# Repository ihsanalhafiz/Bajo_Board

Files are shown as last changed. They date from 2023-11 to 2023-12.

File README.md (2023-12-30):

# Bajo Board (Low Cost Seismic Imaging Sensor Systems based on MEMS Accelerometer)

The Bajo Board or accelerometer sensor system is an integrated sensor system consisting of accelerometer, inclinometer and seismometer sensors. The accelerometer sensor is used to detect vibrations and carry out seismic imaging. The inclinometer sensor is used to detect tilt from monitoring stations. The seismometer sensor is used to calculate the SI value to detect early if there is an earthquake or tectonic activity and send a warning if an earthquake with MMI level 5 or above is detected. It requires voltage input with industry standart 24V, and will provide interface in RS232.

# [Updated] Deploy location and results

## Deploy location
This board was deployed in the pilot project Indonesia Cable Based Tsunameter in NTT, Indonesia in 2 locations. These sensors are used for the seismic imaging, so it receives the accelerometer raw data and not directly converted to earthquake magnitude. that is the ongoing research. 

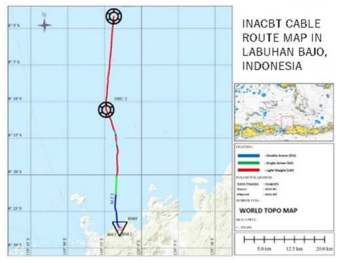
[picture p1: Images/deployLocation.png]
deploy


reference

M. A. Purwoadi, Y. Anantasena, W. W. Pandoe, J. Widodo and A. E. Sakya, "Introduction to Indonesian Cable-based Subsea Tsunameter," 2023 IEEE Underwater Technology (UT), Tokyo, Japan, 2023, pp. 1-6, doi: 10.1109/UT49729.2023.10103368.

## Results from earthquakes
these results show accelerometer raw data from earthquakes.
### First earthquake
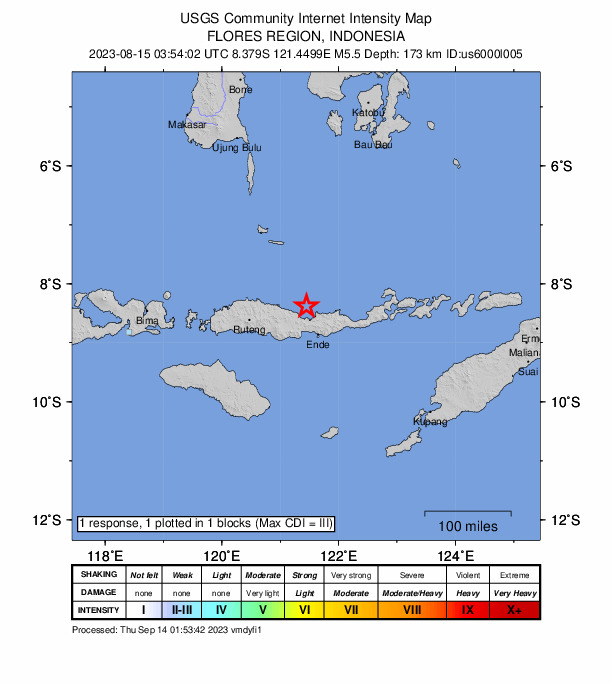
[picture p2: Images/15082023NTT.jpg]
firstEarthquake

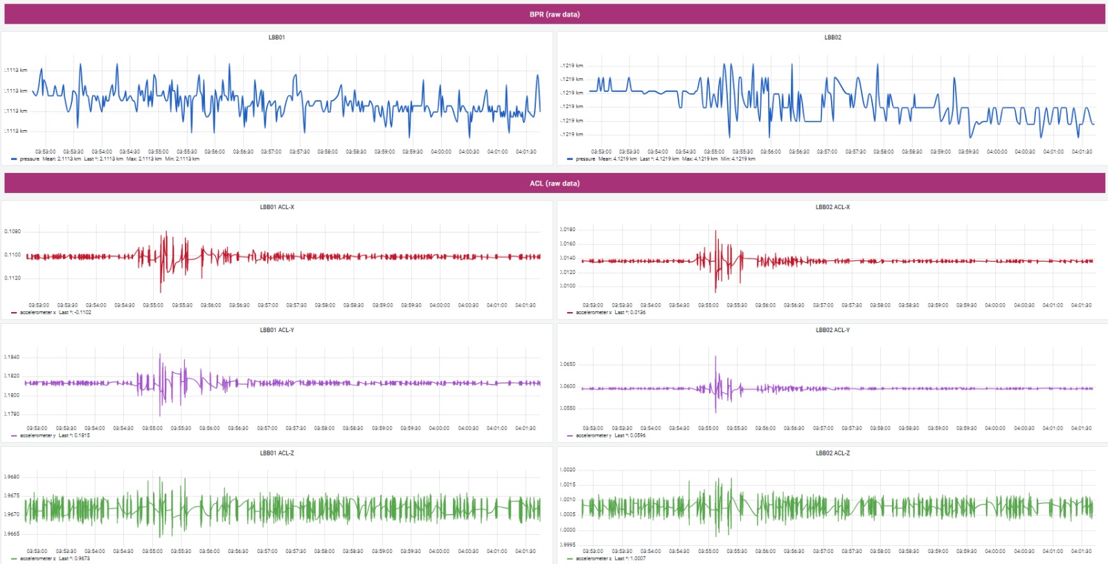
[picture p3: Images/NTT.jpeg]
responseFisrt


### Second earthquake
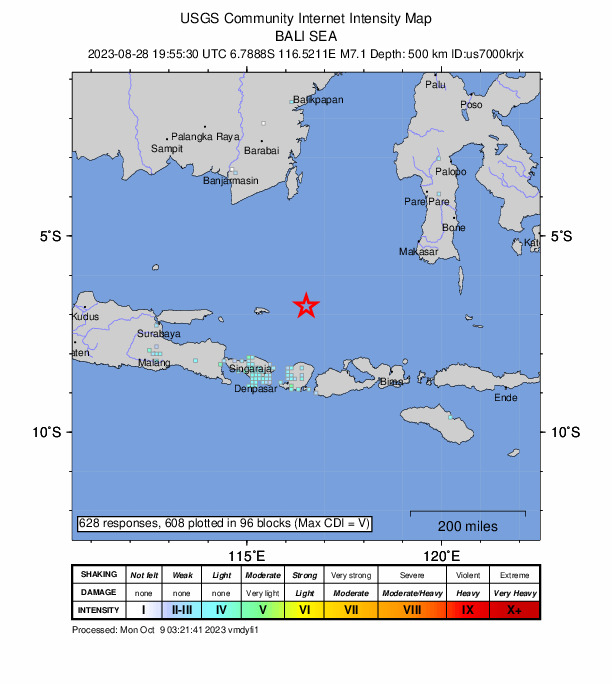
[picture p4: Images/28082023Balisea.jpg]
secondEarthquake

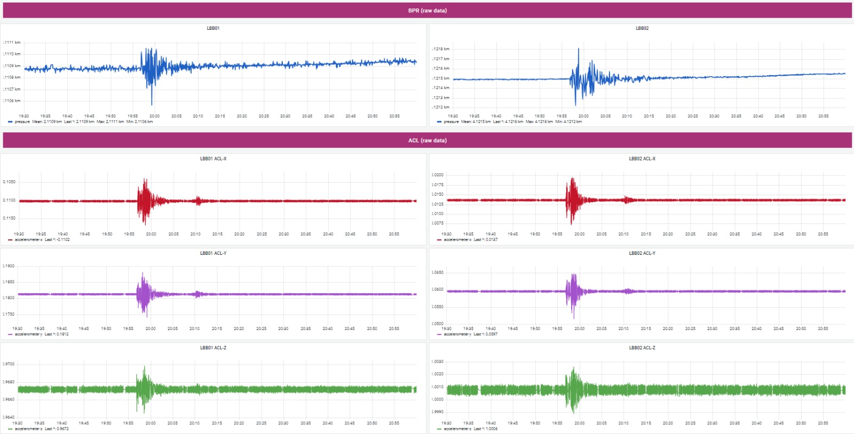
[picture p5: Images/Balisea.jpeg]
responseSecond


# Block Diagram System

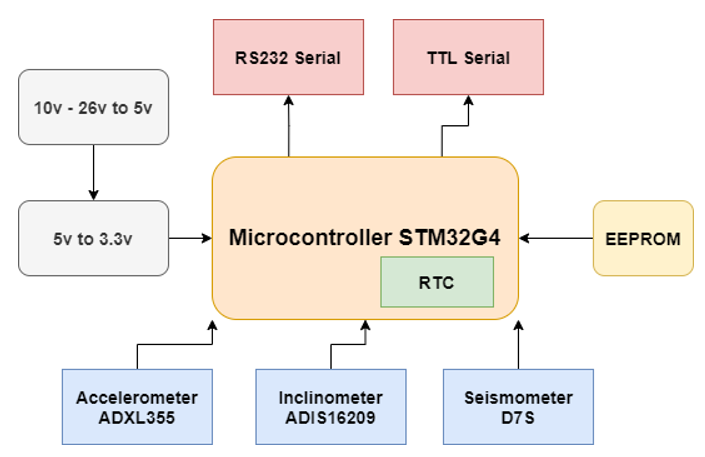
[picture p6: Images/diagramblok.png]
block diagram


The accelerometer sensor system has three main sensor elements, namely the accelerometer sensor, inclinometer and seismometer. In the picture above, a comprehensive block design for the accelerometer sensor system is designed which consists of the sensors used and supporting components such as power supply, digital components and communication components. The ADXL355 accelerometer sensor is a 3-axis accelerometer sensor based on MEMS which is usually used to detect vibrations and one of them is for seismic imaging according to the datasheet. The ADIS16209 inclinometer sensor is a sensor for detecting 2-axis tilt, namely x and y, which is intended to detect the tilt of the OBU installation in the CBT system, as well as to monitor whether there is a change in tilt when the OBU has been deployed and is operating. The D7S seismometer sensor is an Omron vibration sensor that can be integrated to detect earthquake vibrations by calculating the SI value of an earthquake event. This sensor is also equipped with an interruption process when there is an earthquake event with an MMI of 5 and above, so that by detecting the SI value an earthquake can be detected and a warning sent.

# Hardware Part

board

boardwithcasing

case
[Link to buy the case AN-2851-AB](https://www.digikey.com/en/products/detail/bud-industries/AN-2851-AB/5775342)

## PCB Design
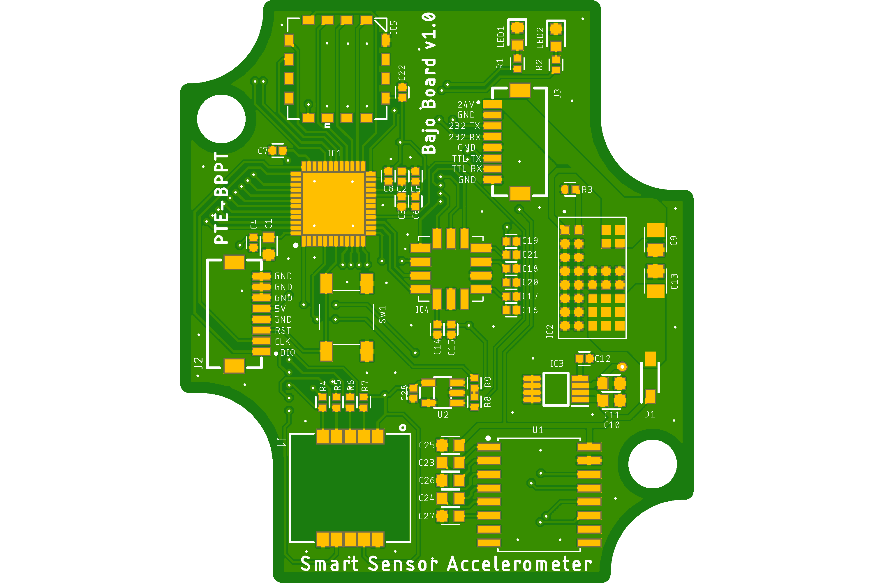
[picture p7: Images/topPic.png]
top

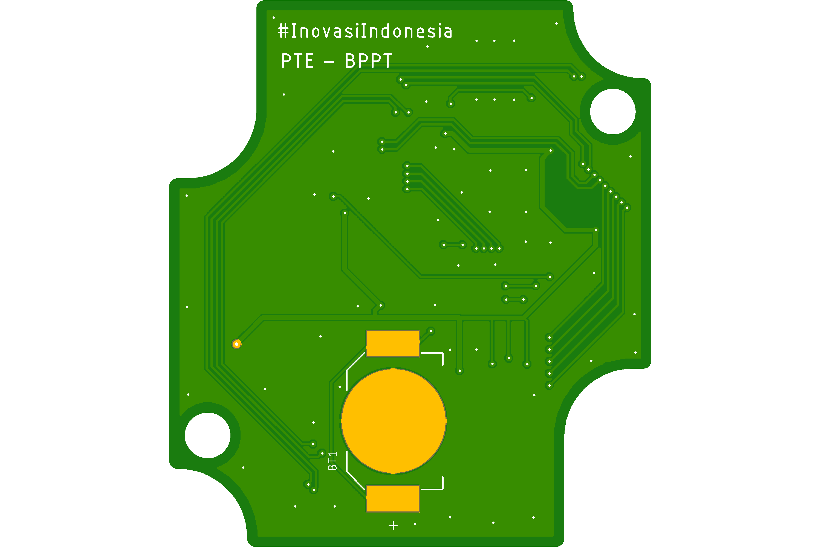
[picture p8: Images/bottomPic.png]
bottom


[Gerber File](https://github.com/ihsanalhafiz/Bajo_Board/blob/master/Hardware_Part/SeismicAccelerometerSystem_Gerber.zip)

[Bill of Materials](https://github.com/ihsanalhafiz/Bajo_Board/blob/master/Hardware_Part/BoM.xlsx)

[Centroid File](https://github.com/ihsanalhafiz/Bajo_Board/tree/master/Hardware_Part/CentroidFile)

# Software Part

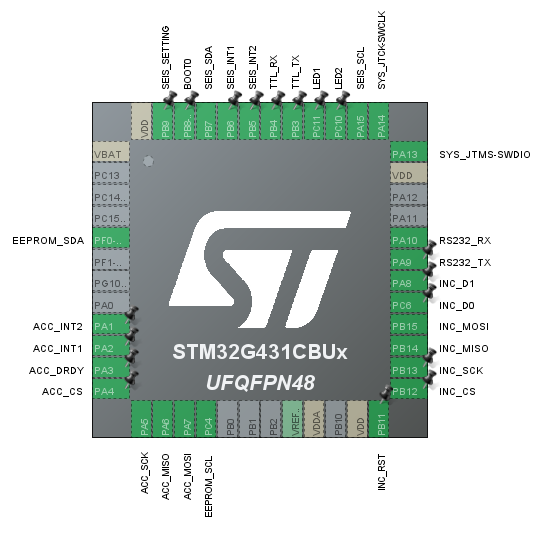
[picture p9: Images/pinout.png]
pinout


## List Bajo EEPROM Variable
No. | Address | Variables | Expected Value | Number of Bytes | Information
:---: | :---: | --- | --- | :---: | ---
1 | 0x00 | id | 0 - 100 | 1 | ID of the sensor
2 | 0x01 | range_accelerometer | 1, 2, or 3 (2g, 4g, 8g) | 1 | Sensor reading range
3 | 0x02 | odr_accelerometer | 0 - 10 (4000hz - 4hz) | 1 | Output accelerometer data output
4 | 0x03 | autorun | 1 (auto run) or 0 (manual run/need command) | 1 | Autorun or manual accelerometer sensor
5 | 0x04 | raw | 1 (decimal) or 0 (micro g) | 1 | Accelerometer output data unit
6 | 0x05 | offsetx | ± 32768 | 4 | Offset value for x calibration
7 | 0x09 | offsety | ± 32768 | 4 | Offset value for y calibration
8 | 0x10 | offsetz | ± 32768 | 4 | Offset value for z calibration

## List of Bajo Serial Process
No. | Command | Syntax | Response/Output | Function/Description
--- | --- | --- | --- | ---
1 | STOP | AT+STOP | "stop" | Stops ADXL355 sensor Measurement
2 | START | AT+START | "start" | Starting Measurement of ADXL355 sensor
3 | ID= | AT+ID=<1-100> | "OK" | Enter the Bajo Board ID in the EEPROM
4 | ID? | AT+ID? | "ID: (ID value)" | View Bajo Board ID data
5 | RANGE= | AT+RANGE=<1-3> | "OK" | Setting the ADXL355 sensor range value <br /> 1 = Range 2g <br /> 2 = Range 4g <br /> 3 = Range 8g
6 | RANGE? | AT+RANGE? | "RANGE:(range value)" | View the ADXL355 sensor range
7 | ODR= | AT+ODR=<1-10> | "OK" | Setting the Output Data Rate (ODR) value of the ADXL355 sensor <br /> 0 = 4000Hz <br /> 1 = 2000Hz <br /> 2 = 1000Hz <br /> 3 = 500Hz <br /> 4 = 250Hz <br /> 5 = 125Hz <br /> 6 = 62Hz <br /> 7 = 31Hz <br /> 8 = 16Hz <br /> 9 = 8Hz <br /> 10 = 4Hz
8 | ODR? | AT+ODR? | "ODR: (odr value)" | View the ADXL355 sensor Data Rate Output
9 | AUTO= | AT+AUTO=<1-2> | "OK" | Setting the autorun value <br /> 1 = Start measuring the ADXL355 sensor <br /> 2 = Stop measuring the ADXL355 sensor
10 | AUTO? | AT+AUTO? | "AUTO: (autorun value)" | See Autorun
11 | ACCRESET | AT+ACCRESET | "Reset ADXL355" | Returns ADXL355 sensor settings to original
12 | ST1= | AT+ST1=<0-1> | "ST1 OFF" when value is 0 <br /> "ST1 ON" when value is 1 <br /> "wrong value" when value is more than 1 | ADXL355 sensor Self Test Mode <br /> 0 = Selftest is turned off (low) <br /> 1 = Selftest is turned on (high)
13 | ST2= | AT+ST2=<0-1> | "ST2 OFF" when value is 0 <br /> "ST2 ON" when value is 1 <br /> "wrong value" when value is more than 1 | ADXL355 sensor Self Test Mode <br /> 0 = Selftest is turned off (low) <br /> 1 = Selftest is turned on (high) <br /> Provides an electrostatic force on the ADXL355 mechanical sensor which impacts changes in output from its response to pressure. The response (change in power) that is visible is the difference in output V when ST2 is high and ST2 is low. After the Selftest is carried out, set the two ST pins to low to return to normal operation
14 | RAW= | AT+RAW=<0-1> | "OK" | Setting the ADXL355 sensor data output type <br /> 0 = mg output <br /> 1 = raw output
15 | RAW? | AT+RAW? | "RAW: (RAW value)" | View the ADXL355 sensor data output type
16 | OFFSETX= | AT+OFFSETX=<-32000 to 32000> | "OK, (offset value without minus)" | Set the ADXL355 sensor offset value on the X axis, the offset value interval is -32000 to 32000
17 | OFFSETX? | AT+OFFSETX? | "OFFSETX:(offset value)" | View the offset value of the ADXL355 sensor on the X axis
18 | OFFSETY= | AT+OFFSETY=<-32000 to 32000> | "OK, (offset value without minus)" | Set the ADXL355 sensor offset value on the Y axis, the offset value interval is -32000 to 32000
19 | OFFSETY? | AT+OFFSETY? | "OFFSETY:(offset value)" | View the offset value of the ADXL355 sensor on the Y axis
20 | OFFSETZ= | AT+OFFSETZ=<-32000 to 32000> | "OK, (offset value without minus)" | Set the ADXL355 sensor offset value on the Z axis, the offset value interval is -32000 to 32000
21 | OFFSETZ? | AT+OFFSETZ? | "OFFSETZ:(offset value)" | View the offset value of the ADXL355 sensor on the Z axis
22 | TEMP= | AT+TEMP=<0-1> | "OK" |Set the TEMP output on the ADXL355 sensor <br /> 0 = TEMP output is displayed <br /> 1 = TEMP output is not displayed
23 | TEMP? | AT+TEMP? | "TEMP:(TEMP status value)" | View the TEMP output status on the ADXL355 sensor
24 | INCSTATUS? | AT+INCSTATUS? | "inclino status: (inclino status value in hexadecimal of 2 bytes)" | View the status of the ADIS16209 sensor
25 | INCX? | AT+INCX? | "inclino x: (x-axis value in hexadecimal of 2 bytes)" | View the x-axis degree value of the ADIS16209 sensor
26 | INCY? | AT+INCY? | "inclino y: (y-axis value in hexadecimal of 2 bytes)" | View the y-axis degree value of the ADIS16209 sensor
27 | INCROT? | AT+INCROT? | "inclino rot: (rotation value in hexadecimal of 2 bytes)" | View the rotation degree value of the ADIS16209 sensor
28 | INCSUPOUT? | AT+INCSUPOUT? | "inclino supp out: (rotation value in hexadecimal of 2 bytes)" | View the digital supply voltage measurement value on the VDD pin of the ADIS16209 sensor
29 | INCRESET | AT+INCRESET | "inclino reset…." | Reset the ADIS16209 sensor settings
30 | INCREV | AT+INCREV | "inclino revision: (revision status value in hexadecimal of 2 bytes)" | View the Revision status of the ADIS16209 sensor
31 | INCMSC? | AT+INCMSC? | "inclino MSC_OUT: (MSC status value in hexadecimal of 2 bytes))" | View the data ready and control cell status of the ADIS 16209 sensor
32 | REBOOT | AT+REBOOT | "Reboot..." | Perform a System Reset

# License
license

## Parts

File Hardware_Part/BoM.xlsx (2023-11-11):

Designator | Manufacturer Part Number | Qty | Link
C2, C4, C7, C8, C14, C16, C18, C19 | C0402C104K4RACTU | 8 | https://www.digikey.com/en/products/detail/kemet/C0402C104K4RACTU/789661
C22 | CGA2B1X7R1C104K050BC | 1 | https://www.digikey.com/product-detail/en/tdk-corporation/CGA2B1X7R1C104K050BC/445-5613-1-ND/2443653
C28 | C0402C104Z4VAC7867 | 1 | https://www.digikey.com/en/products/detail/kemet/C0402C104Z4VAC7867/411045
R4, R5, R6, R7, R8, R9 | RC0402FR-0710KL | 6 | https://www.digikey.com/product-detail/en/yageo/RC0402FR-0710KL/311-10.0KLRCT-ND/729470
C12 | CC0402KRX7R7BB103 | 1 | https://www.digikey.com/product-detail/en/yageo/CC0402KRX7R7BB103/311-1042-1-ND/302959
C6 | C0402C103K3RACTU | 1 | https://www.digikey.com/en/products/detail/kemet/C0402C103K3RACTU/416041
R3 | ERJ-2RKF1912X | 1 | https://www.digikey.com/en/products/detail/panasonic-electronic-components/ERJ-2RKF1912X/192187
C3, C5, C15, C17, C20, C21 | CC0402KRX5R5BB105 | 6 | https://www.digikey.com/en/products/detail/yageo/CC0402KRX5R5BB105/2833603
C23, C24, C25, C26, C27 | CGA3E1X7R1C105K080AC | 5 | https://www.digikey.com/en/products/detail/tdk-corporation/CGA3E1X7R1C105K080AC/3949775
C9 | C0805C105K5RACTU | 1 | https://www.digikey.com/product-detail/en/kemet/C0805C105K5RACTU/399-7409-1-ND/3317443
C10, C11 | C1608X5R1C225K080AB | 2 | https://www.digikey.com/product-detail/en/tdk-corporation/C1608X5R1C225K080AB/445-5157-1-ND/2093772
C13 | C0805C225K8RACTU | 1 | https://www.digikey.com/product-detail/en/kemet/C0805C225K8RACTU/399-3522-1-ND/789662
U2 | 24LC01BT-I/OT | 1 | https://www.digikey.com/en/products/detail/microchip-technology/24LC01BT-I-OT/318651
C1 | C0603C475K9PACTU | 1 | https://www.digikey.com/en/products/detail/kemet/C0603C475K9PACTU/754775
J2, J3 | 5013310807 | 2 | https://www.digikey.com/en/products/detail/molex/501331-0807/1531535
R1, R2 | RCS0402560RFKED | 2 | https://www.digikey.com/en/products/detail/vishay-dale/RCS0402560RFKED/5867669
IC5 | ADIS16209CCCZ | 1 | https://www.digikey.com/products/en/sensors-transducers/motion-sensors-inclinometers/533?k=ADIS16209
IC3 | ADP1715ARMZ-3.3-R7 | 1 | https://www.digikey.com/product-detail/en/analog-devices-inc/ADP1715ARMZ-3.3-R7/ADP1715ARMZ-3.3-R7CT-ND/1630787
IC4 | ADXL355BEZ-RL7 | 1 | https://www.mouser.co.id/ProductDetail/Analog-Devices/ADXL355BEZ-RL7/?qs=vcbl%252BK4rRleGsXj6gXOU1w==
LED1 | APT1608SURCK | 1 | https://www.digikey.com/en/products/detail/kingbright/APT1608SURCK/1747522
LED2 | APT1608SYCK | 1 | https://www.digikey.com/en/products/detail/kingbright/APT1608SYCK/1747523
BT1 | BK-916-TR | 1 | https://www.digikey.com/en/products/detail/mpd-memory-protection-devices/BK-916-TR/6200238
J1 | D7S-A0001 | 1 | https://www.digikey.com/product-detail/en/omron-electronics-inc-emc-div/D7S-A0001/Z5835CT-ND/6133945
IC2 | LTM8021IV#PBF | 1 | https://www.digikey.com/product-detail/en/analog-devices-inc/LTM8021IV-PBF/LTM8021IV-PBF-ND/1859094
U1 | MAX232ECDW | 1 | https://www.digikey.com/en/products/detail/texas-instruments/MAX232ECDW/1511009
D1 | MBR0540T1G | 1 | https://www.digikey.com/en/products/detail/on-semiconductor/MBR0540T1G/918576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
IC1 | STM32G431CBU6 | 1 | https://www.digikey.com/en/products/detail/stmicroelectronics/STM32G431CBU6/10231569
SW1 | TL3342F160QG/TR | 1 | https://www.digikey.com/en/products/detail/e-switch/TL3342F160QG-TR/379003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

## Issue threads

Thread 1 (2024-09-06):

Erro opening EAGLE PCB design

Arakistech, 2024-09-06:
Hi, I am interested in the board, but I get an error when trying to open EAGLE PCB design.

Regards,

Ivan

ihsanalhafiz, 2024-09-07:
Hi, please tell me what the error is and what version of Eagle you use. i used Autodesk eagle 9.6.2 when I designed it.

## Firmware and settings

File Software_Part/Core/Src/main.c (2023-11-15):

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
/* Includes ------------------------------------------------------------------*/
#include "main.h"
#include "cmsis_os.h"

/* USER CODE BEGIN Includes */
#include "parameter_universal.h"
/* USER CODE END Includes */

I2C_HandleTypeDef hi2c1;
I2C_HandleTypeDef hi2c2;

IWDG_HandleTypeDef hiwdg;

RTC_HandleTypeDef hrtc;

SPI_HandleTypeDef hspi1;
SPI_HandleTypeDef hspi2;

UART_HandleTypeDef huart1;
UART_HandleTypeDef huart2;
DMA_HandleTypeDef hdma_usart1_rx;
DMA_HandleTypeDef hdma_usart2_rx;

/* Definitions for defaultTask */
osThreadId_t defaultTaskHandle;
const osThreadAttr_t defaultTask_attributes = {
  .name = "defaultTask",
  .priority = (osPriority_t) osPriorityNormal,
  .stack_size = 512 * 4
};
/* Definitions for accTask */
osThreadId_t accTaskHandle;
const osThreadAttr_t accTask_attributes = {
  .name = "accTask",
  .priority = (osPriority_t) osPriorityNormal,
  .stack_size = 512 * 4
};
/* Definitions for serialTask */
osThreadId_t serialTaskHandle;
const osThreadAttr_t serialTask_attributes = {
  .name = "serialTask",
  .priority = (osPriority_t) osPriorityNormal,
  .stack_size = 512 * 4
};
/* Definitions for ttlTask */
osThreadId_t ttlTaskHandle;
const osThreadAttr_t ttlTask_attributes = {
  .name = "ttlTask",
  .priority = (osPriority_t) osPriorityNormal,
  .stack_size = 256 * 4
};
/* Definitions for watchdogTask */
osThreadId_t watchdogTaskHandle;
const osThreadAttr_t watchdogTask_attributes = {
  .name = "watchdogTask",
  .priority = (osPriority_t) osPriorityNormal,
  .stack_size = 256 * 4
};
/* Definitions for serialQueue */
osMessageQueueId_t serialQueueHandle;
const osMessageQueueAttr_t serialQueue_attributes = {
  .name = "serialQueue"
};
/* Definitions for ttlQueue */
osMessageQueueId_t ttlQueueHandle;
const osMessageQueueAttr_t ttlQueue_attributes = {
  .name = "ttlQueue"
};
/* Definitions for rtcBinarySem */
osSemaphoreId_t rtcBinarySemHandle;
const osSemaphoreAttr_t rtcBinarySem_attributes = {
  .name = "rtcBinarySem"
};
/* Definitions for intBinarySem */
osSemaphoreId_t intBinarySemHandle;
const osSemaphoreAttr_t intBinarySem_attributes = {
  .name = "intBinarySem"
};
/* Definitions for RS232BinarySem */
osSemaphoreId_t RS232BinarySemHandle;
const osSemaphoreAttr_t RS232BinarySem_attributes = {
  .name = "RS232BinarySem"
};
/* USER CODE BEGIN PV */

uint32_t defaultTaskTimer;
uint32_t accTaskTimer;
uint32_t serialTaskTimer;
uint32_t ttlTaskTimer;
uint32_t incTaskTimer;

float Ax,Ay,Az;
float roll;
float pitch;

/*
 * Variable stored in EEPROM
 */
uint8_t id;
uint8_t range_accelerometer;
uint8_t odr_accelerometer;
uint8_t autorun;
uint8_t raw;
int offsetx;
int offsety;
int offsetz;
uint8_t flagtemp;

/* USER CODE END PV */

void SystemClock_Config(void);
static void MX_GPIO_Init(void);
static void MX_DMA_Init(void);
static void MX_I2C2_Init(void);
static void MX_RTC_Init(void);
static void MX_SPI1_Init(void);
static void MX_SPI2_Init(void);
static void MX_USART1_UART_Init(void);
static void MX_USART2_UART_Init(void);
static void MX_I2C1_Init(void);
static void MX_IWDG_Init(void);
void StartDefaultTask(void *argument);
void StartAccTask(void *argument);
void StartSerialTask(void *argument);
void StartTtlTask(void *argument);
void StartWatchdogTask(void *argument);

static void MX_NVIC_Init(void);
/**
  * @brief  The application entry point.
  * @retval int
  */
int main(void)
{
  /* MCU Configuration--------------------------------------------------------*/

  /* Reset of all peripherals, Initializes the Flash interface and the Systick. */
  HAL_Init();

  /* Configure the system clock */
  SystemClock_Config();

  /* Initialize all configured peripherals */
  MX_GPIO_Init();
  MX_DMA_Init();
  MX_I2C2_Init();
  MX_RTC_Init();
  MX_SPI1_Init();
  MX_SPI2_Init();
  MX_USART1_UART_Init();
  MX_USART2_UART_Init();
  MX_I2C1_Init();
  MX_IWDG_Init();

  /* Initialize interrupts */
  MX_NVIC_Init();
  /* Init scheduler */
  osKernelInitialize();

  /* USER CODE BEGIN RTOS_MUTEX */
  /* add mutexes, ... */
  /* USER CODE END RTOS_MUTEX */

  /* Create the semaphores(s) */
  /* creation of rtcBinarySem */
  rtcBinarySemHandle = osSemaphoreNew(1, 1, &rtcBinarySem_attributes);

  /* creation of intBinarySem */
  intBinarySemHandle = osSemaphoreNew(1, 1, &intBinarySem_attributes);

  /* creation of RS232BinarySem */
  RS232BinarySemHandle = osSemaphoreNew(1, 1, &RS232BinarySem_attributes);

  /* USER CODE BEGIN RTOS_SEMAPHORES */
  /* add semaphores, ... */
  /* USER CODE END RTOS_SEMAPHORES */

  /* USER CODE BEGIN RTOS_TIMERS */
  /* start timers, add new ones, ... */
  /* USER CODE END RTOS_TIMERS */

  /* Create the queue(s) */
  /* creation of serialQueue */
  serialQueueHandle = osMessageQueueNew (2, 30, &serialQueue_attributes);

  /* creation of ttlQueue */
  ttlQueueHandle = osMessageQueueNew (4, 30, &ttlQueue_attributes);

  /* USER CODE BEGIN RTOS_QUEUES */
  /* add queues, ... */
  /* USER CODE END RTOS_QUEUES */

  /* Create the thread(s) */
  /* creation of defaultTask */
  defaultTaskHandle = osThreadNew(StartDefaultTask, NULL, &defaultTask_attributes);

  /* creation of accTask */
  accTaskHandle = osThreadNew(StartAccTask, NULL, &accTask_attributes);

  /* creation of serialTask */
  serialTaskHandle = osThreadNew(StartSerialTask, NULL, &serialTask_attributes);

  /* creation of ttlTask */
  ttlTaskHandle = osThreadNew(StartTtlTask, NULL, &ttlTask_attributes);

  /* creation of watchdogTask */
  watchdogTaskHandle = osThreadNew(StartWatchdogTask, NULL, &watchdogTask_attributes);

  /* USER CODE BEGIN RTOS_THREADS */
  /* add threads, ... */
  /* USER CODE END RTOS_THREADS */

  /* USER CODE BEGIN RTOS_EVENTS */
  /* add events, ... */
  /* USER CODE END RTOS_EVENTS */

  /* Start scheduler */
  osKernelStart();

  /* We should never get here as control is now taken by the scheduler */
  /* Infinite loop */
  /* USER CODE BEGIN WHILE */
  while (1)
  {
    /* USER CODE END WHILE */

    /* USER CODE BEGIN 3 */
  }
  /* USER CODE END 3 */
}

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
/* USER CODE BEGIN 4 */


/*
 * fungsi Callback Serial ketika data yang diterima telah lengkap.
 * fungsi ini dieksekusi setiap data masuk baik di mode interupsi maupun DMA
 */
void HAL_UART_RxCpltCallback(UART_HandleTypeDef *huart) {
	if (huart->Instance == USART1) //Serial RS232
	{
		SERIAL_Callback();
	}
	if (huart->Instance == USART2) //Serial TTL
	{
		TTL_Callback();
	}
}

/*
 * Handler for EXTI
 * fungsi callback untuk eksternal interupsi dari pin yang telah diatur
 * */
void HAL_GPIO_EXTI_Callback(uint16_t GPIO_Pin) {
	if (GPIO_Pin == GPIO_PIN_6) {
		serial_printf("$%u,03,earthquake_detected\r\n", id);
	}
}

void HAL_RTC_AlarmAEventCallback(RTC_HandleTypeDef *hrtc) { //alarm A pada mode buoy dibuat per menit
	osSemaphoreRelease(rtcBinarySemHandle);
}

/* USER CODE END 4 */

/* USER CODE BEGIN Header_StartDefaultTask */
/**
  * @brief  Function implementing the defaultTask thread.
  * @param  argument: Not used
  * @retval None
  */
/* USER CODE END Header_StartDefaultTask */
void StartDefaultTask(void *argument)
{
  /* USER CODE BEGIN 5 */
	//RTC_TimeTypeDef RTCMicro;
	//RTC_DateTypeDef RTCDateMicro;
	uint8_t buf[2];
	char buff[100];
	uint8_t checksum;
	//uint8_t buf2[2];
	//uint8_t buf3[2];
	//uint16_t buf;
	serial_printf("Bajo Board v1.0.0 by PTE BPPT \r\n");
	HAL_GPIO_WritePin(GPIOB, INC_RST_Pin, GPIO_PIN_SET);
	adis16209_read_reg(PROD_ID, buf, 2);
	serial_printf("inclino: %x %x\r\n",buf[0], buf[1]);
	serial_printf("done\r\n");
	HAL_GPIO_WritePin(GPIOC, LED1_Pin, GPIO_PIN_SET);
	osSemaphoreAcquire(rtcBinarySemHandle, 100);

  /* Infinite loop */
  for(;;)
  {
	  defaultTaskTimer = osKernelGetTickCount();

	  if (osSemaphoreGetCount(rtcBinarySemHandle) > 0) {
		  osSemaphoreAcquire(rtcBinarySemHandle, 100);
		  HAL_GPIO_TogglePin(GPIOC, LED2_Pin);
		  /*
			adis16209_read_reg(0x3C, buf2, 2);
			serial_printf("inclino status: %x %x\r\n",buf2[0], buf2[1]);
			if(buf2[0] == 0x00 && buf[1] == 0x00 ){
				adis16209_read_reg(0x0C, buf3, 2);
				serial_printf("inclino x: %x %x\r\n",buf3[0], buf3[1]);

			}
			else{
				adis16209_reset();
			}
		   */

		  //roll = CalculateRoll(Ay, Az);
		  //pitch = CalculatePitch(Ax, Ay, Az);


		  //serial_printf("x: %f y: %f z: %f\r\n",xdata, ydata, zdata);

		  if(flagtemp == 1){
			  pitch = 180.0 * atan (Ax/sqrt(Ay*Ay + Az*Az))/M_PI;
			  roll = 180.0 * atan (Ay/sqrt(Ax*Ax + Az*Az))/M_PI;

			  memset(buff, 0x00, sizeof(buff));
			  //sprintf(buff, "%02d,1,%f,%f,%f,%f", id, xdata/(float)1000000.0, ydata/(float)1000000.0, zdata/(float)1000000.0,temp);
			  sprintf(buff, "%02d,2,%f,%f", id, roll, pitch);
			  checksum=buff[0];
			  for(int i=1; i<strlen(buff); i++) checksum=checksum ^ buff[i];
			  //sprintf(buff, "$%02d,1,%f,%f,%f,%f*%02X\r\n", id, xdata/(float)1000000.0, ydata/(float)1000000.0, zdata/(float)1000000.0, temp, checksum);
			  sprintf(buff, "$%02d,2,%f,%f*%02X\r\n", id, roll, pitch, checksum);
			  //serial_printf("%s",buff);
			  osSemaphoreAcquire(RS232BinarySemHandle,100);
			  serial_puts(buff);
			  osSemaphoreRelease(RS232BinarySemHandle);

		  }
	  }
    osDelay(1);
  }
  /* USER CODE END 5 */
}

/* USER CODE BEGIN Header_StartAccTask */
/**
* @brief Function implementing the accTask thread.
* @param argument: Not used
* @retval None
*/
/* USER CODE END Header_StartAccTask */
void StartAccTask(void *argument)
{
  /* USER CODE BEGIN StartAccTask */
	uint8_t checksum;
	char buff[100];
	int i;
	float temp;


	InitEEPROM();
	adxl355_range(range_accelerometer);
	adxl355_odr(odr_accelerometer);
/*
	if(offsetx < 32768 && offsetx>-32768) adxl355_offset_x(offsetx);
	if(offsety < 32768 && offsety>-32768) adxl355_offset_y(offsety);
	if(offsetz < 32768 && offsetz>-32768) adxl355_offset_z(offsetz);
*/
	if(autorun == 1) adxl355_start_measurement();
	if(autorun == 0) adxl355_stop_measurement();

  /* Infinite loop */
  for(;;)
  {
	  accTaskTimer = osKernelGetTickCount();
	  /*
	   * Read status sensor for get data ready status
	   */
	  if(adxl355_status()){ //data ready == 1
		  //read sensor data
		  //xdata = adxl355_x_axis();
		  //ydata = adxl355_y_axis();
		  //zdata = adxl355_z_axis();
		  //temp=adxl355_temperature();
		  adxl355_readData(&Ax, &Ay, &Az, &temp, range_accelerometer);
		  //generate checksum
		  //Tipe data=1 untuk data accelerometer format: $01,1,Ax,Ay,Az,temp*CheckSum\r\n
		  memset(buff, 0x00, sizeof(buff));
		  //sprintf(buff, "%02d,1,%f,%f,%f,%f", id, xdata/(float)1000000.0, ydata/(float)1000000.0, zdata/(float)1000000.0,temp);
		  sprintf(buff, "%02d,1,%f,%f,%f,%.2f", id, Ax, Ay, Az, temp);
		  checksum=buff[0];
		  for(i=1; i<strlen(buff); i++) checksum=checksum ^ buff[i];
		  //sprintf(buff, "$%02d,1,%f,%f,%f,%f*%02X\r\n", id, xdata/(float)1000000.0, ydata/(float)1000000.0, zdata/(float)1000000.0, temp, checksum);
		  sprintf(buff, "$%02d,1,%f,%f,%f,%.2f*%02X\r\n", id, Ax, Ay, Az, temp, checksum);
		  //serial_printf("%s",buff);
		  osSemaphoreAcquire(RS232BinarySemHandle,100);
		  serial_puts(buff);
		  osSemaphoreRelease(RS232BinarySemHandle);
	  }
	  else{
		 osDelay(1);
	  }
  }
  /* USER CODE END StartAccTask */
}

/* USER CODE BEGIN Header_StartSerialTask */
/**
* @brief Function implementing the serialTask thread.
* @param argument: Not used
* @retval None
*/
/* USER CODE END Header_StartSerialTask */
void StartSerialTask(void *argument)
{
  /* USER CODE BEGIN StartSerialTask */
	osStatus_t status;
	uint8_t queuenumber;
	char bufferserial[30] = "";
	SERIAL_Init();

  /* Infinite loop */
  for(;;)
  {
	  serialTaskTimer = osKernelGetTickCount();

		queuenumber = osMessageQueueGetCount(serialQueueHandle);
		if (queuenumber > 0) {
			memset(bufferserial, 0, sizeof(bufferserial));
			status = osMessageQueueGet(serialQueueHandle, &bufferserial, NULL, 1000); // wait for message
			if (status == osOK) {
				SERIAL_Process(bufferserial);
			}
		}

    osDelay(1);
  }
  /* USER CODE END StartSerialTask */
}

/* USER CODE BEGIN Header_StartTtlTask */
/**
* @brief Function implementing the ttlTask thread.
* @param argument: Not used
* @retval None
*/
/* USER CODE END Header_StartTtlTask */
void StartTtlTask(void *argument)
{
  /* USER CODE BEGIN StartTtlTask */
	uint8_t checksum;
	osStatus_t status;
	int i;
	uint8_t queuenumber;
	char bufferttl[11] = "";
	TTL_Init();
	char buff[100];
  /* Infinite loop */
  for(;;)
  {
	  ttlTaskTimer = osKernelGetTickCount();

		queuenumber = osMessageQueueGetCount(ttlQueueHandle);
		if (queuenumber > 0) {
			memset(bufferttl, 0, sizeof(bufferttl));
			status = osMessageQueueGet(ttlQueueHandle, &bufferttl, NULL, 1000); // wait for message
			if (status == osOK) {
				//TTL_Process(bufferttl);
				  memset(buff, 0x00, sizeof(buff));
				  //sprintf(buff, "%02d,1,%f,%f,%f,%f", id, xdata/(float)1000000.0, ydata/(float)1000000.0, zdata/(float)1000000.0,temp);
				  sprintf(buff, "%02d,4,%s", id, bufferttl);
				  checksum=buff[0];
				  for(i=1; i<strlen(buff); i++) checksum=checksum ^ buff[i];
				  //sprintf(buff, "$%02d,1,%f,%f,%f,%f*%02X\r\n", id, xdata/(float)1000000.0, ydata/(float)1000000.0, zdata/(float)1000000.0, temp, checksum);
				  sprintf(buff, "$%02d,4,%s*%02X\r\n", id, bufferttl, checksum);

				osSemaphoreAcquire(RS232BinarySemHandle,100);
				serial_puts(buff);
				osSemaphoreRelease(RS232BinarySemHandle);
			}
		}

    osDelay(1);
  }
  /* USER CODE END StartTtlTask */
}

/* USER CODE BEGIN Header_StartWatchdogTask */
/**
* @brief Function implementing the watchdogTask thread.
* @param argument: Not used
* @retval None
*/
/* USER CODE END Header_StartWatchdogTask */
void StartWatchdogTask(void *argument)
{
  /* USER CODE BEGIN StartWatchdogTask */
	uint8_t ResetOnHang;

	uint8_t flagdefault = 0;
	uint8_t flagacc = 0;
	uint8_t flagserial = 0;
	uint8_t flagttl = 0;

  /* Infinite loop */
  for(;;)
  {
	  ResetOnHang = 0;

		if ((osKernelGetTickCount() - defaultTaskTimer) > 5000) {
			if (flagdefault == 0) {
				flagdefault = 1;
				serial_printf("$Hangdefault\r\n");
			}
			ResetOnHang = 1;
		} else
			flagdefault = 0;

		if ((osKernelGetTickCount() - accTaskTimer) > 5000) {
			if (flagacc == 0) {
				flagacc = 1;
				serial_printf("$Hangacc\r\n");
			}
			ResetOnHang = 1;
		} else
			flagacc = 0;

		if ((osKernelGetTickCount() - serialTaskTimer) > 5000) {
			if (flagserial == 0) {
				flagserial = 1;
				serial_printf("$Hangserial\r\n");
			}
			ResetOnHang = 1;
		} else
			flagserial = 0;

		if ((osKernelGetTickCount() - ttlTaskTimer) > 5000) {
			if (flagttl == 0) {
				flagttl = 1;
				serial_printf("$Hangttl\r\n");
			}
			ResetOnHang = 1;
		} else
			flagttl = 0;

		if (!ResetOnHang) {
			if (HAL_IWDG_Refresh(&hiwdg) != HAL_OK) {
				// /* Refresh Error*/
				Error_Handler();
			}
		}
		//else NVIC_SystemReset();
    osDelay(1);
  }
  /* USER CODE END StartWatchdogTask */
}

 /**
  * @brief  Period elapsed callback in non blocking mode
  * @note   This function is called  when TIM6 interrupt took place, inside
  * HAL_TIM_IRQHandler(). It makes a direct call to HAL_IncTick() to increment
  * a global variable "uwTick" used as application time base.
  * @param  htim : TIM handle
  * @retval None
  */
void HAL_TIM_PeriodElapsedCallback(TIM_HandleTypeDef *htim)
{
  if (htim->Instance == TIM6) {
    HAL_IncTick();
  }
}

/**
  * @brief  This function is executed in case of error occurrence.
  * @retval None
  */
void Error_Handler(void)
{
  /* USER CODE BEGIN Error_Handler_Debug */
  /* User can add his own implementation to report the HAL error return state */
  __disable_irq();
  while (1)
  {
  }
  /* USER CODE END Error_Handler_Debug */
}

#ifdef  USE_FULL_ASSERT
/**
  * @brief  Reports the name of the source file and the source line number
  *         where the assert_param error has occurred.
  * @param  file: pointer to the source file name
  * @param  line: assert_param error line source number
  * @retval None
  */
void assert_failed(uint8_t *file, uint32_t line)
{
  /* USER CODE BEGIN 6 */
  /* User can add his own implementation to report the file name and line number,
     ex: printf("Wrong parameters value: file %s on line %d\r\n", file, line) */
  /* USER CODE END 6 */
}
#endif /* USE_FULL_ASSERT */

/************************ (C) COPYRIGHT STMicroelectronics *****END OF FILE****/

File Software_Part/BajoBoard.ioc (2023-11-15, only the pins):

Mcu.UserName=STM32G431CBUx
PA1.GPIO_Label=ACC_INT2
PA1.Signal=GPXTI1
PA10.GPIO_Label=RS232_RX
PA10.Signal=USART1_RX
PA13.Signal=SYS_JTMS-SWDIO
PA14.Signal=SYS_JTCK-SWCLK
PA2.GPIO_Label=ACC_INT1
PA2.Signal=GPXTI2
PA3.GPIO_Label=ACC_DRDY
PA3.Signal=GPXTI3
PA4.GPIO_Label=ACC_CS
PA4.Signal=GPIO_Output
PA5.GPIO_Label=ACC_SCK
PA5.Signal=SPI1_SCK
PA6.GPIO_Label=ACC_MISO
PA6.Signal=SPI1_MISO
PA7.GPIO_Label=ACC_MOSI
PA7.Signal=SPI1_MOSI
PA9.GPIO_Label=RS232_TX
PA9.Signal=USART1_TX
PB11.GPIO_Label=INC_RST
PB11.Signal=GPIO_Output
PB12.GPIO_Label=INC_CS
PB12.Signal=GPIO_Output
PB13.GPIO_Label=INC_SCK
PB13.Signal=SPI2_SCK
PB14.GPIO_Label=INC_MISO
PB14.Signal=SPI2_MISO
PB15.GPIO_Label=INC_MOSI
PB15.Signal=SPI2_MOSI
PB3.GPIO_Label=TTL_TX
PB3.Signal=USART2_TX
PB4.GPIO_Label=TTL_RX
PB4.Signal=USART2_RX
PB5.GPIO_Label=SEIS_INT2
PB5.Signal=GPXTI5
PB6.GPIO_Label=SEIS_INT1
PB6.Signal=GPXTI6
PB7.GPIO_Label=SEIS_SDA
PB7.Signal=I2C1_SDA
PB8-BOOT0.GPIO_Label=SEIS_SCL
PB8-BOOT0.Signal=I2C1_SCL
PB9.GPIO_Label=SEIS_SETTING
PB9.Signal=GPIO_Output
PC10.GPIO_Label=LED2
PC10.Signal=GPIO_Output
PC11.GPIO_Label=LED1
PC11.Signal=GPIO_Output
PC4.GPIO_Label=EEPROM_SCL
PC4.Signal=I2C2_SCL
PF0-OSC_IN.GPIO_Label=EEPROM_SDA
PF0-OSC_IN.Signal=I2C2_SDA

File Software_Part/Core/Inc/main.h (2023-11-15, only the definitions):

#define EEPROM_SDA_Pin GPIO_PIN_0
#define EEPROM_SDA_GPIO_Port GPIOF
#define ACC_INT2_Pin GPIO_PIN_1
#define ACC_INT2_GPIO_Port GPIOA
#define ACC_INT2_EXTI_IRQn EXTI1_IRQn
#define ACC_INT1_Pin GPIO_PIN_2
#define ACC_INT1_GPIO_Port GPIOA
#define ACC_INT1_EXTI_IRQn EXTI2_IRQn
#define ACC_DRDY_Pin GPIO_PIN_3
#define ACC_DRDY_GPIO_Port GPIOA
#define ACC_DRDY_EXTI_IRQn EXTI3_IRQn
#define ACC_CS_Pin GPIO_PIN_4
#define ACC_CS_GPIO_Port GPIOA
#define ACC_SCK_Pin GPIO_PIN_5
#define ACC_SCK_GPIO_Port GPIOA
#define ACC_MISO_Pin GPIO_PIN_6
#define ACC_MISO_GPIO_Port GPIOA
#define ACC_MOSI_Pin GPIO_PIN_7
#define ACC_MOSI_GPIO_Port GPIOA
#define EEPROM_SCL_Pin GPIO_PIN_4
#define EEPROM_SCL_GPIO_Port GPIOC
#define INC_RST_Pin GPIO_PIN_11
#define INC_RST_GPIO_Port GPIOB
#define INC_CS_Pin GPIO_PIN_12
#define INC_CS_GPIO_Port GPIOB
#define INC_SCK_Pin GPIO_PIN_13
#define INC_SCK_GPIO_Port GPIOB
#define INC_MISO_Pin GPIO_PIN_14
#define INC_MISO_GPIO_Port GPIOB
#define INC_MOSI_Pin GPIO_PIN_15
#define INC_MOSI_GPIO_Port GPIOB
#define RS232_TX_Pin GPIO_PIN_9
#define RS232_TX_GPIO_Port GPIOA
#define RS232_RX_Pin GPIO_PIN_10
#define RS232_RX_GPIO_Port GPIOA
#define LED2_Pin GPIO_PIN_10
#define LED2_GPIO_Port GPIOC
#define LED1_Pin GPIO_PIN_11
#define LED1_GPIO_Port GPIOC
#define TTL_TX_Pin GPIO_PIN_3
#define TTL_TX_GPIO_Port GPIOB
#define TTL_RX_Pin GPIO_PIN_4
#define TTL_RX_GPIO_Port GPIOB
#define SEIS_INT2_Pin GPIO_PIN_5
#define SEIS_INT2_GPIO_Port GPIOB
#define SEIS_INT2_EXTI_IRQn EXTI9_5_IRQn
#define SEIS_INT1_Pin GPIO_PIN_6
#define SEIS_INT1_GPIO_Port GPIOB
#define SEIS_INT1_EXTI_IRQn EXTI9_5_IRQn
#define SEIS_SDA_Pin GPIO_PIN_7
#define SEIS_SDA_GPIO_Port GPIOB
#define SEIS_SCL_Pin GPIO_PIN_8
#define SEIS_SCL_GPIO_Port GPIOB
#define SEIS_SETTING_Pin GPIO_PIN_9
#define SEIS_SETTING_GPIO_Port GPIOB

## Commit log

2023-11-15 update format and add software
    [BajoBoard.cfg, BoM.xlsx, SeismicAccelerometerSystem.brd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]
2023-12-30 update name
    [layout.brd, schematic.sch]

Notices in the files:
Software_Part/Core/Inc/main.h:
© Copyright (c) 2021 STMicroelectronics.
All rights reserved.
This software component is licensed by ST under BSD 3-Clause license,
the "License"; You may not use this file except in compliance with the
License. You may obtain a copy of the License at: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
